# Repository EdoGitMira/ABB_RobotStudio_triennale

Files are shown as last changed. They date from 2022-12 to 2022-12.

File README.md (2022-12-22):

[][License]

<div align = center>

# ABB Robot Studio

*Automation of a two parts automotive manufacturing process* <br>
*Designing / drawing of customized grippers*

<br>

### Team
  
[][Marco] 
[][Edoardo]

<br>
<br>

## Showcase

<br>
       
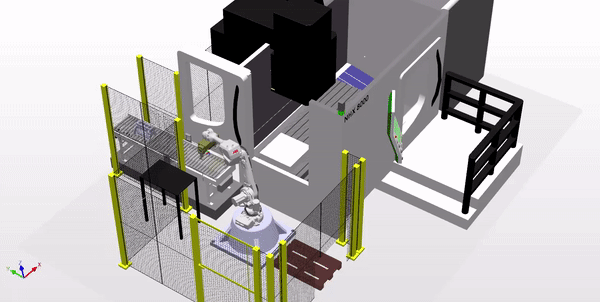
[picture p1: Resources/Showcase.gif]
Showcase


*Accelerated animation showing the entire process*

<br>
<br>

## Implementation

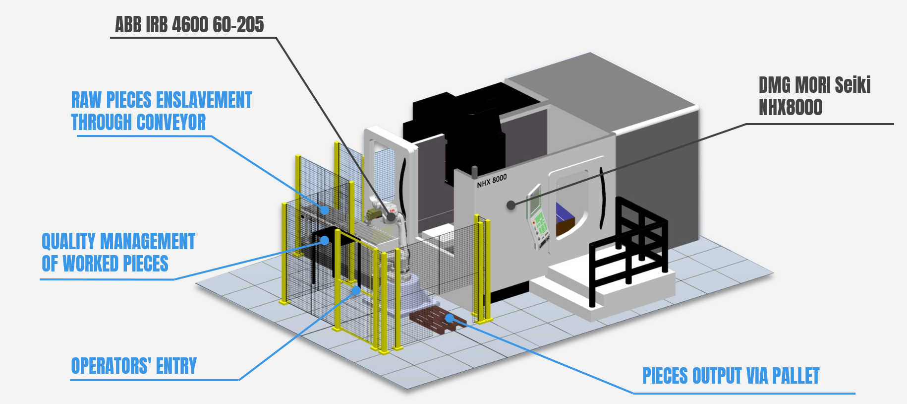
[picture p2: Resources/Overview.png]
Overview


<br>

### Transportation

| *Arrival of New Parts* | *Dispensing of Finished Parts onto Pallet*
|:---:|:---:
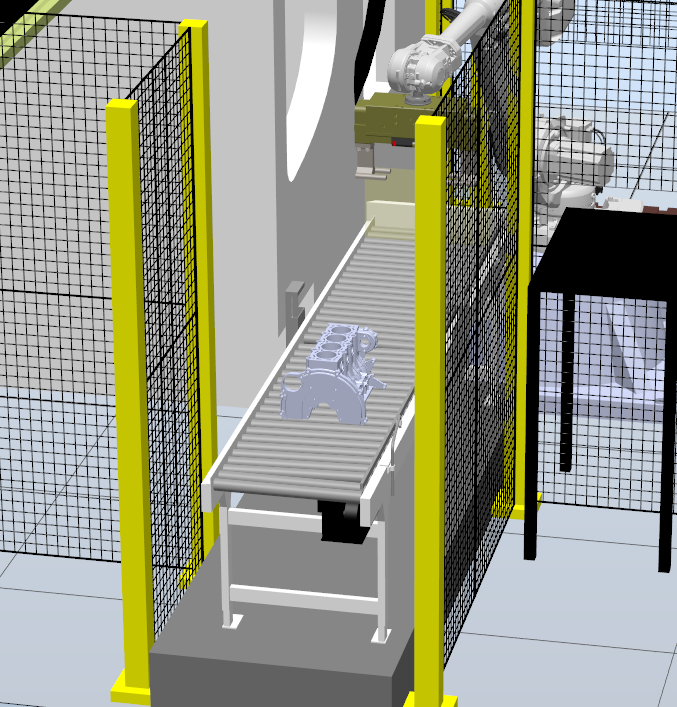
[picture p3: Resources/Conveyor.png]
Conveyor
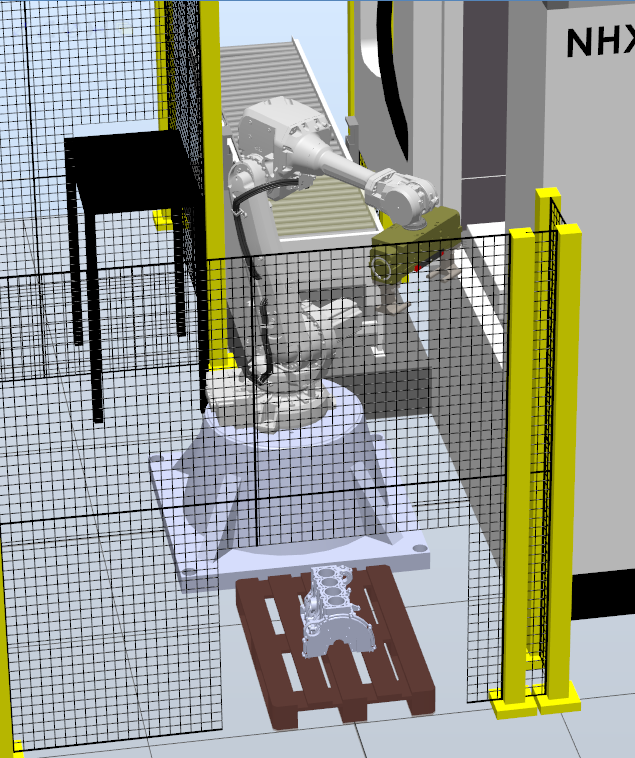
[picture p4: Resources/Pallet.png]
Pallet
|        | 

<br>

### Workpiece Clamping

| XSR201 | XSR202
|:---:|:---:
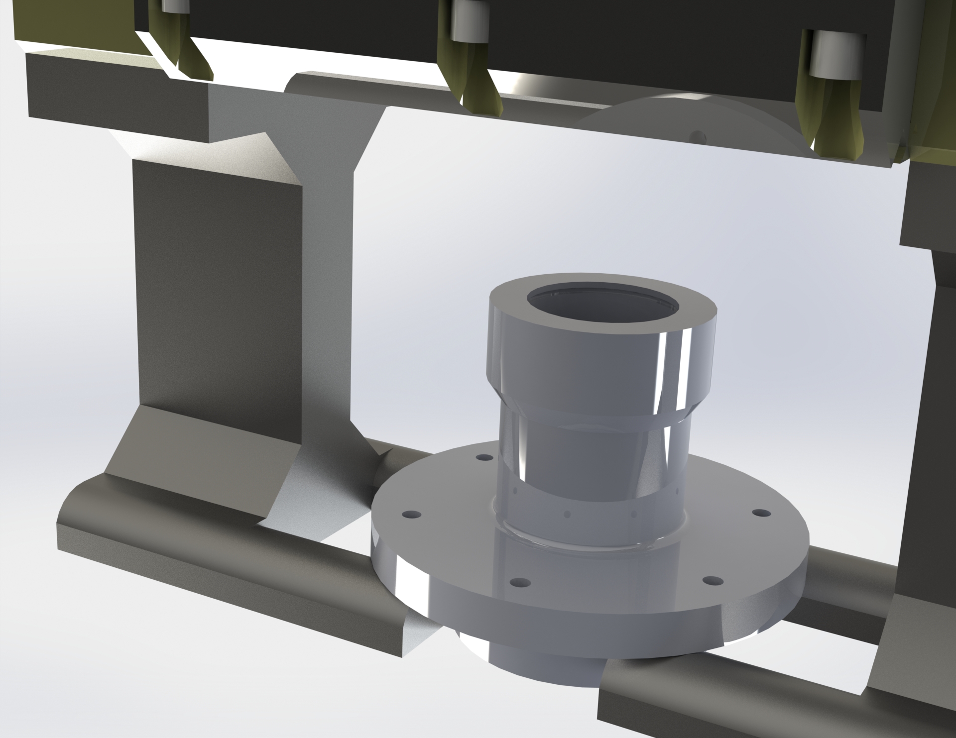
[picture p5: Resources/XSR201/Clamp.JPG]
Clamp 201
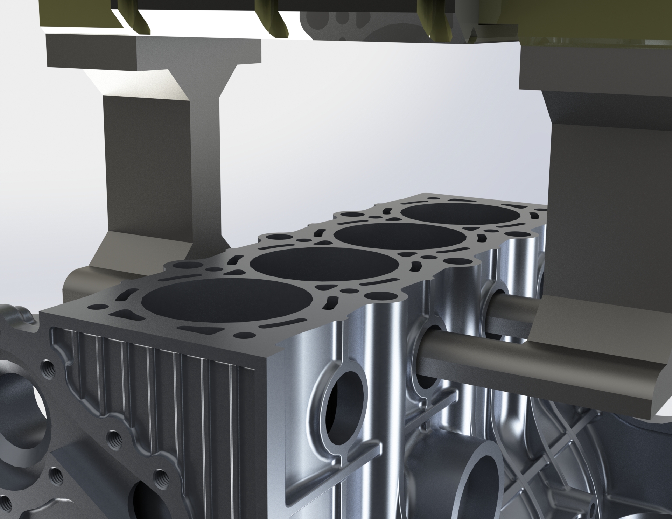
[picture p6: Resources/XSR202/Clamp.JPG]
Clamp 202
|  | 

<br>

### Robot Path

| XSR201 | XSR202
|:---:|:---:
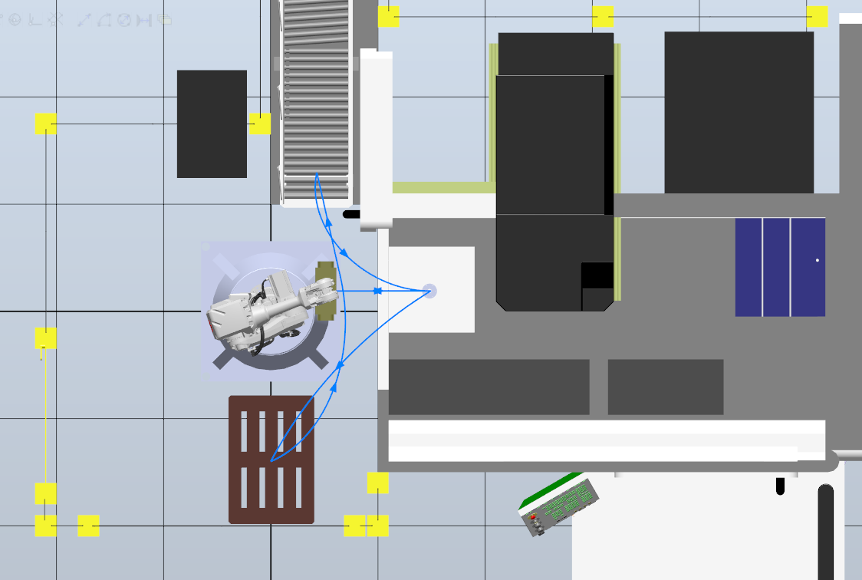
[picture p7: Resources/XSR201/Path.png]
Path 201
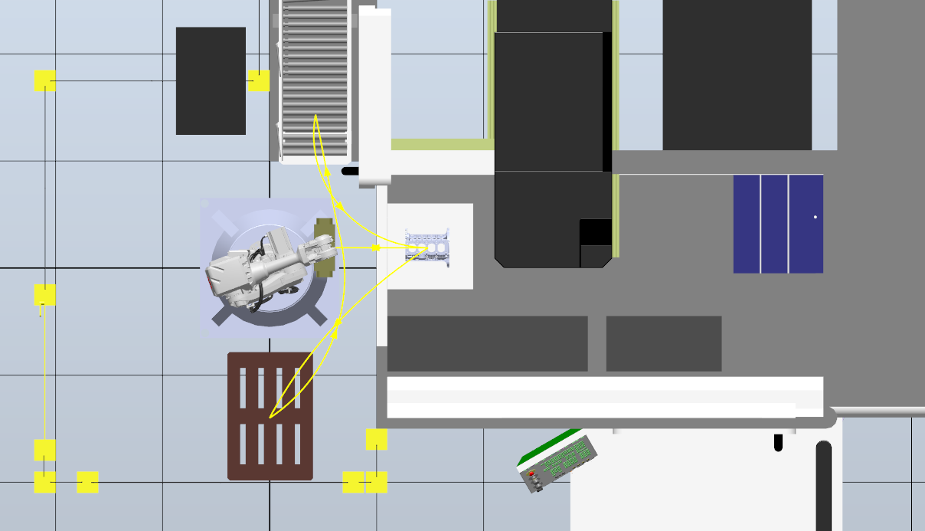
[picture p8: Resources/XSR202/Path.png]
Path 202
|  | 

</div>

<!----------------------------------------------------------------------------->

[Edoardo]: https://github.com/EdoGitMira
[Marco]: https://github.com/marco-milanesi

[License]: LICENSE

<!----------------------------------{ Images }--------------------------------->

[Overview]: Resources/Overview.png
[Showcase]: Resources/Showcase.gif
[Conveyor]: Resources/Conveyor.png
[Pallet]: Resources/Pallet.png

[Clamp 201]: Resources/XSR201/Clamp.JPG
[Path 201]: Resources/XSR201/Path.png

[Clamp 202]: Resources/XSR202/Clamp.JPG
[Path 202]: Resources/XSR202/Path.png

<!---------------------------------{ Badges }---------------------------------->

[Badge License]: https://img.shields.io/badge/License-MIT-yellow.svg?style=for-the-badge

[Badge Edoardo]: https://img.shields.io/badge/Edoardo_Mirandola-8a61c7?style=for-the-badge
[Badge Marco]: https://img.shields.io/badge/Marco_Milanesi-4776c1?style=for-the-badge

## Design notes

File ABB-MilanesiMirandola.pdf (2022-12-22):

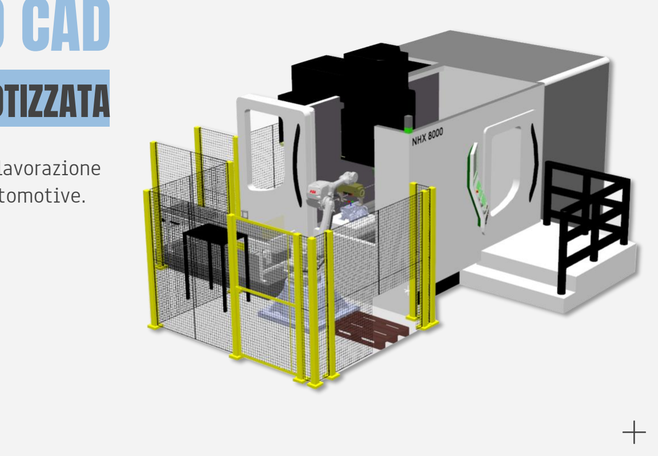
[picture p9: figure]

# PROGETTO ISOLA ROBOTIZZATA

Automazione di un processo di lavorazione meccanica di due particolari automotive.

# LABORATORIO CAD

# Milanesi Marco Mirandola Edoardo

## CONCEPT DELLA CELLA

## SCELTA GRIPPER

## SCELTA ROBOT

## PROGETTAZIONE DELLA CELLA CON IL SW

## PARAMETRI DELLA CELLA

01

02

03

04

05

Milanesi - Mirandola

# LAYOUT

# DELLA CELLA

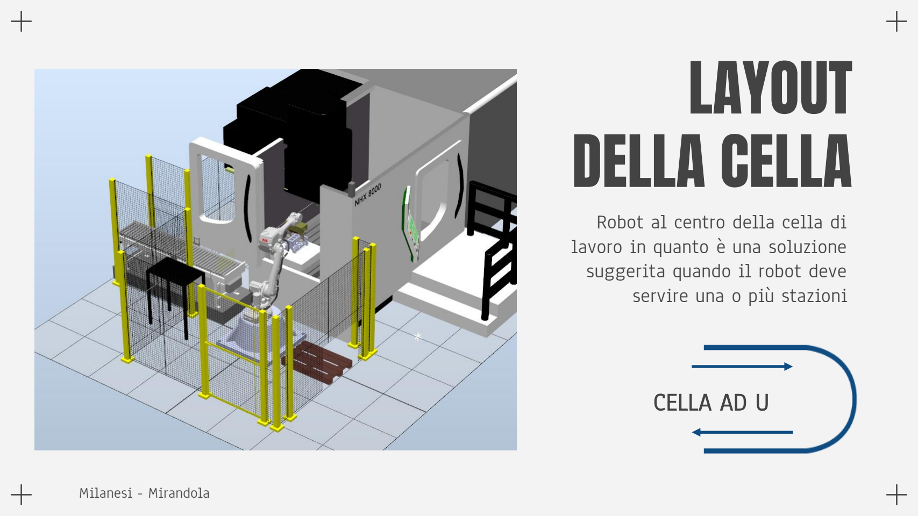
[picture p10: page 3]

## CELLA AD U

Robot al centro della cella di lavoro in quanto è una soluzione suggerita quando il robot deve servire una o più stazioni

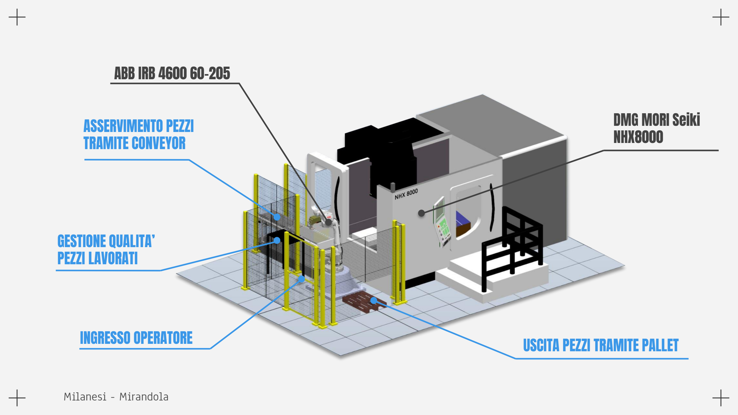
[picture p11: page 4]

DMG MORI Seiki
NHX8000

ABB IRB 4600 60-205

ASSERVIMENTO PEZZI
TRAMITE CONVEYOR

USCITA PEZZI TRAMITE PALLET INGRESSO OPERATORE

GESTIONE QUALITA’
PEZZI LAVORATI

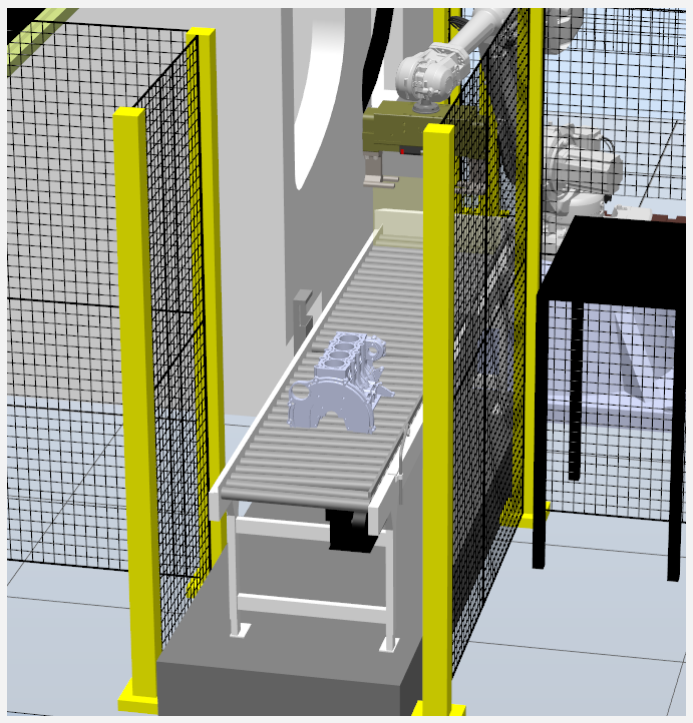
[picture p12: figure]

## Asservimento Pezzi

L’ asservimento pezzi avviene tramite un convogliatore e un PlaneSensor. La simulazione viene azionata dal comando n_MOT / n_XSR201 a seconda del pezzo del pezzo da lavorare.

Se il sensore non rileva la presenza di alcun elemento e non è in corso una lavorazione il convogliatore viene messo in movimento per far sì che un nuovo pezzo arrivi in posizione.

L’istruzione WaitDI FC_Nastro,1 attende che il nastro si arresti prima di procedere

# IMPLEMENTAZIONE DELLA STAZIONE

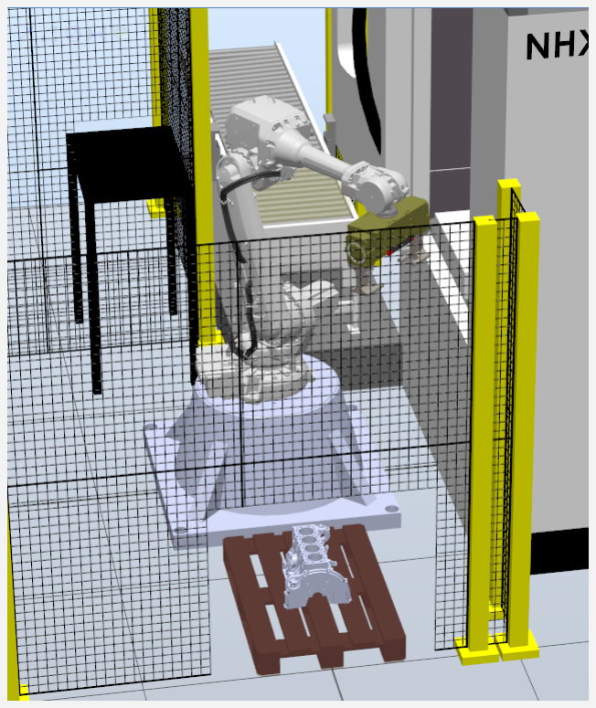
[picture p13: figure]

## Uscita Pezzi

Lo scarico pezzi avviene tramite pallet e un PlaneSensor. Quando il sensore rileva lo scarico del pezzo sul pallet esso può uscire.

Un linear Mover simula l’uscita del pallet che può avvenire tramite un operatore con Transpallet o tramite altro processo automatizzato

Un ulteriore sensore verifica l’effettiva uscita del pallet e inserisce un nuovo pezzo sul conveyor per una simulazione più simile alla realtà.

# IMPLEMENTAZIONE DELLA STAZIONE

## PINZA PARALLELA – SHUNK - 0302120 SPG

# SCELTA GRIPPER

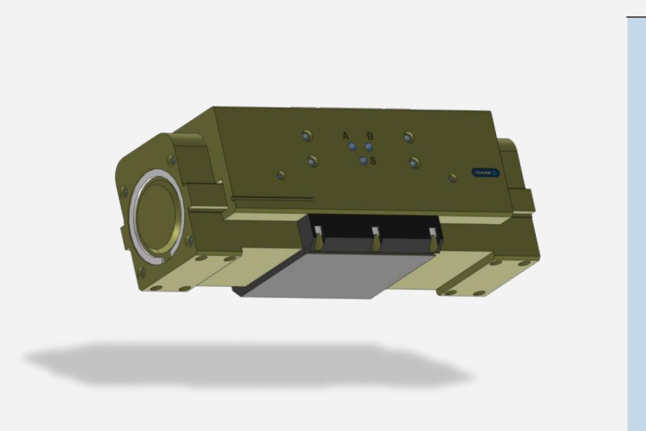
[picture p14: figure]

CORSA PER GRIFFA | 95 | mm
PESO | 35 | Kg
PESO DEL PEZZO
RACCOMANDATO | 50 | Kg

LUNGHEZZA GRIFFE
MASSIMA CONSENTITA | 500 | mm

MASSA MAX. CONSENTITA
PER GRIFFA | 500 | mm

PRINCIPALI PARAMETRI PRESI IN CONSIDERAZIONE

# PRESA PEZZO XSR202

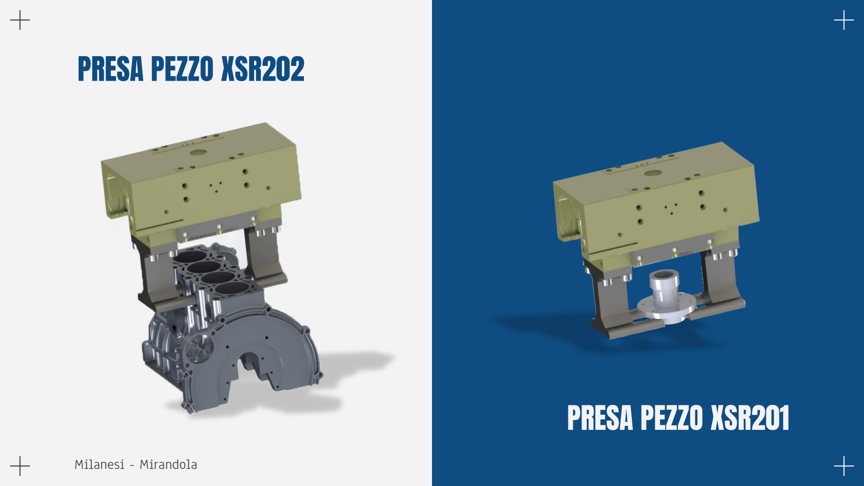
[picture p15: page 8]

# PRESA PEZZO XSR201

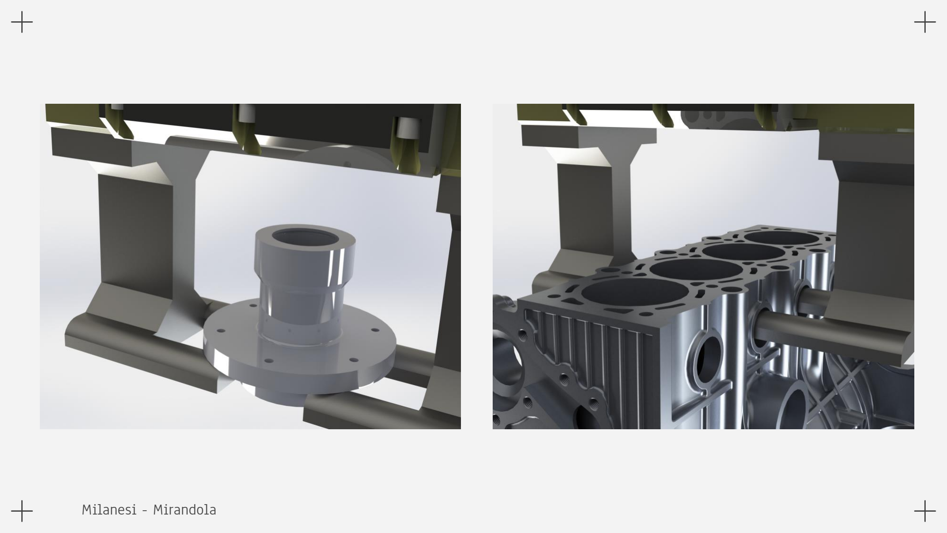
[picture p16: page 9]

# SCELTA DEL ROBOT

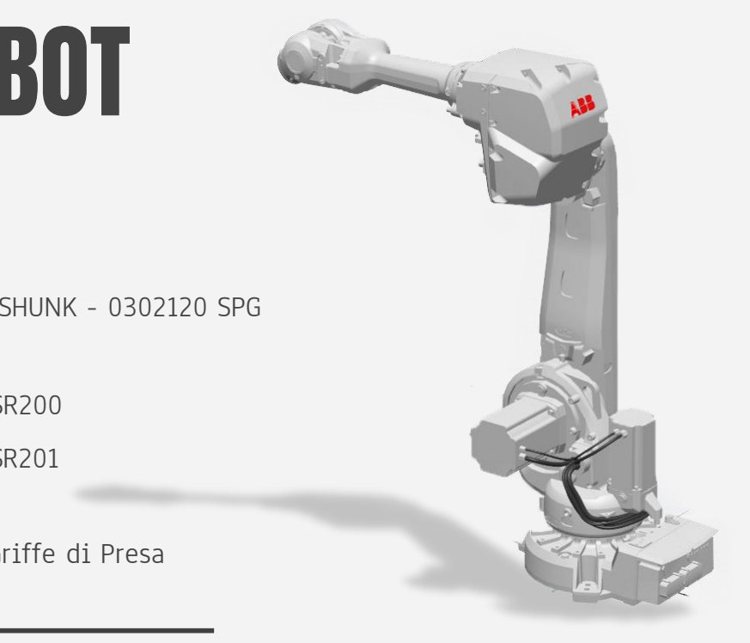
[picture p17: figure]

35 Kg Peso Gripper SHUNK - 0302120 SPG

17 Kg
0,5 Kg
| Peso Pezzo XSR200

# Calcolo del payload

Peso Pezzo XSR201

ROBOT ABB IRB 4600 60-205

4 Kg | Peso Totale Griffe di Presa
56 Kg | 60 Kg

# PROGETTAZIONE DELLA CELLA

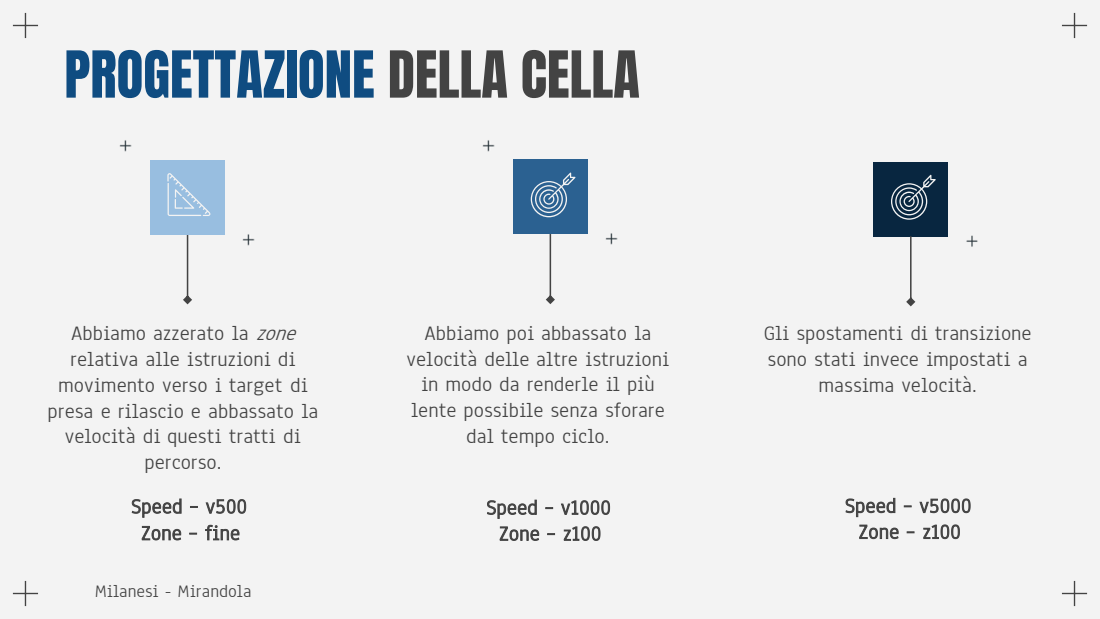
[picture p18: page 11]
Speed – v1000 Zone – z100; Speed – v5000 Zone – z100

Abbiamo azzerato la zone
relativa alle istruzioni di
movimento verso i target di
presa e rilascio e abbassato la
velocità di questi tratti di
percorso.
Speed – v500
Zone – fine

Abbiamo poi abbassato la
velocità delle altre istruzioni
in modo da renderle il più
lente possibile senza sforare
dal tempo ciclo.

Gli spostamenti di transizione
sono stati invece impostati a
massima velocità.

# LOGICA DEL PROGRAMMA

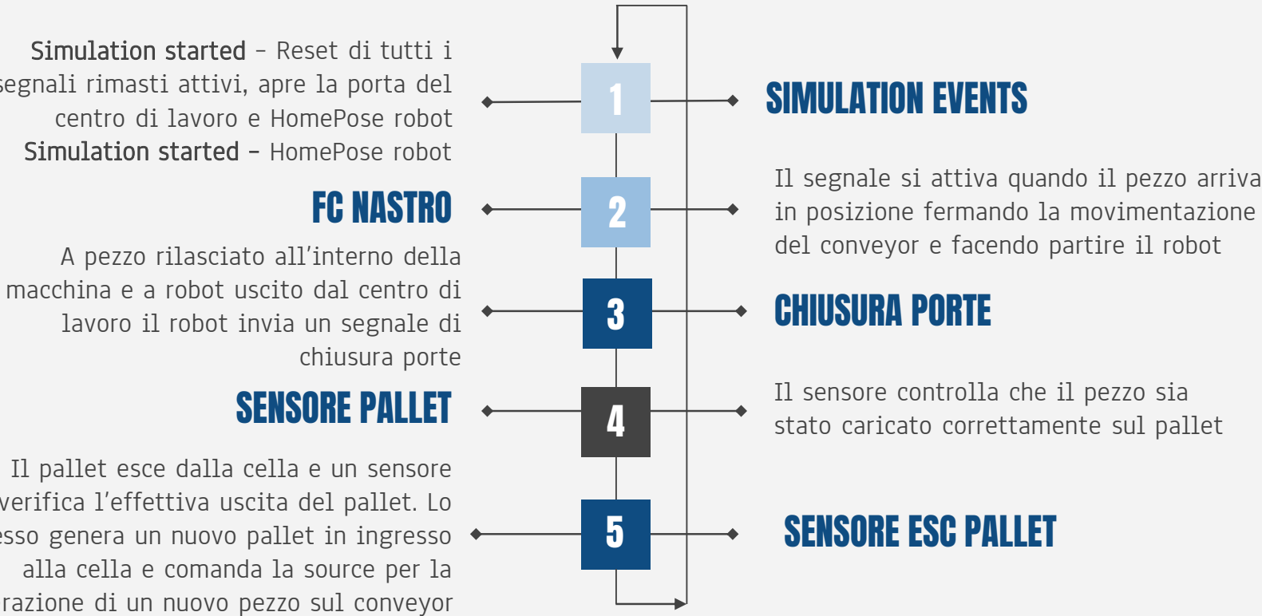
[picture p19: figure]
Simulation started – Reset di tutti i; centro di lavoro e HomePose robot Simulation started – HomePose robot; Il pallet esce dalla cella e un sensore; alla cella e comanda la source per la; A pezzo rilasciato all’interno della macchina e a robot uscito dal centro di lavoro il robot invia un segnale di chiusura porte; in posizione fermando la movimentazione del conveyor e facendo partire il robot; Il sensore controlla che il pezzo sia stato caricato correttamente sul pallet; SIMULATION EVENTS; FC NASTRO; CHIUSURA PORTE; SENSORE ESC PALLET; SENSORE PALLET

segnali rimasti attivi, apre la porta del

verifica l’effettiva uscita del pallet. Lo stesso genera un nuovo pallet in ingresso

generazione di un nuovo pezzo sul conveyor

Il segnale si attiva quando il pezzo arriva

# PATH

PEZZO XSR 202 | PEZZO XSR 201

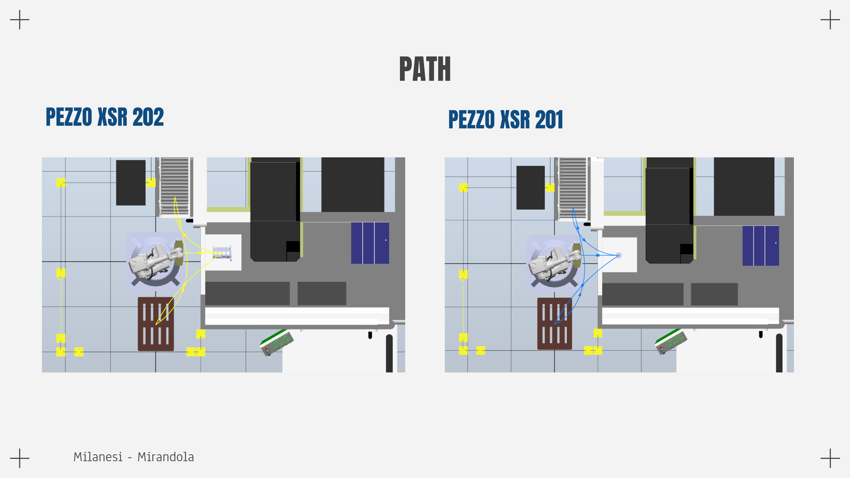
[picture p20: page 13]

# TEMPI E RITMI PRODUTTIVI

Ritmo attività
produttiva

Somma dei tempi di attesa, tempi di giacenza e tempi di trasporto

Tempo che trascorre tra
l’inizio e la fine di una
lavorazione
60 s / pezzo | 56 s
TACKT TIME | TEMPO CICLO | TEMPO DI TRANSITO
CONVEYOR | 4 s
LAVORAZIONE MACCHINA | 45 s
USCITA PEZZO PALLET | 2 s

51 s

CONVEYOR -
MACCHINA 1,8 s

MACCHINA -
PALLET 2,5 s

### 8 h/turno

### 480 pezzi turno

# LABORATORIO CAD

Automazione di un processo di lavorazione meccanica di due particolari automotive. Progettazione di un’isola robotizzata tramite il software ABB Robot Studio

### Milanesi Marco - Mirandola Edoardo

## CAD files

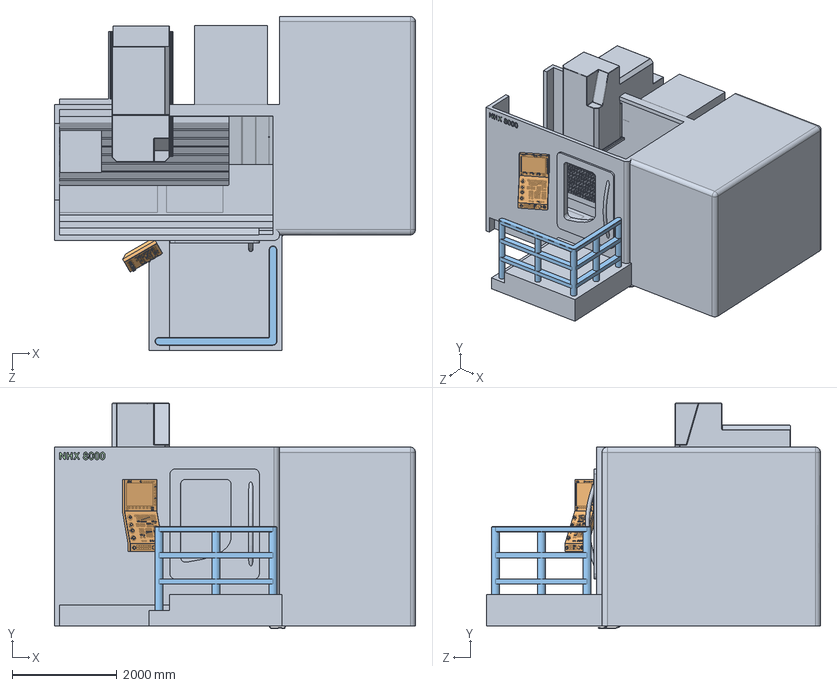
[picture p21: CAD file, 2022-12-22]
disegni_solidworks/assieme_macchina_nhx8000.SLDASM
6904.5 x 4313.0 x 6388.5 mm
macchina
tastiera
ringhiera
logo

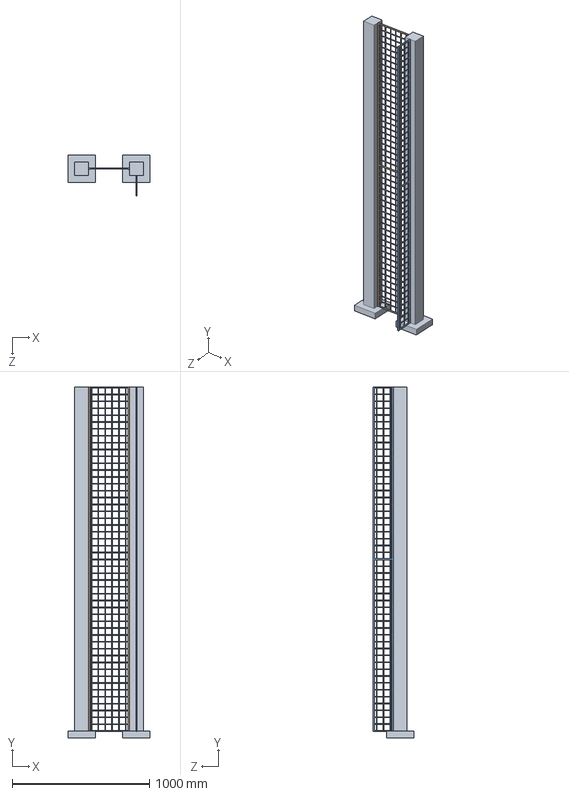
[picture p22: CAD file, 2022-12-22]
disegni_solidworks/bariera_angolo.SLDASM
600.0 x 2555.0 x 300.0 mm
palo_barriera x 2
rete 300
rete200

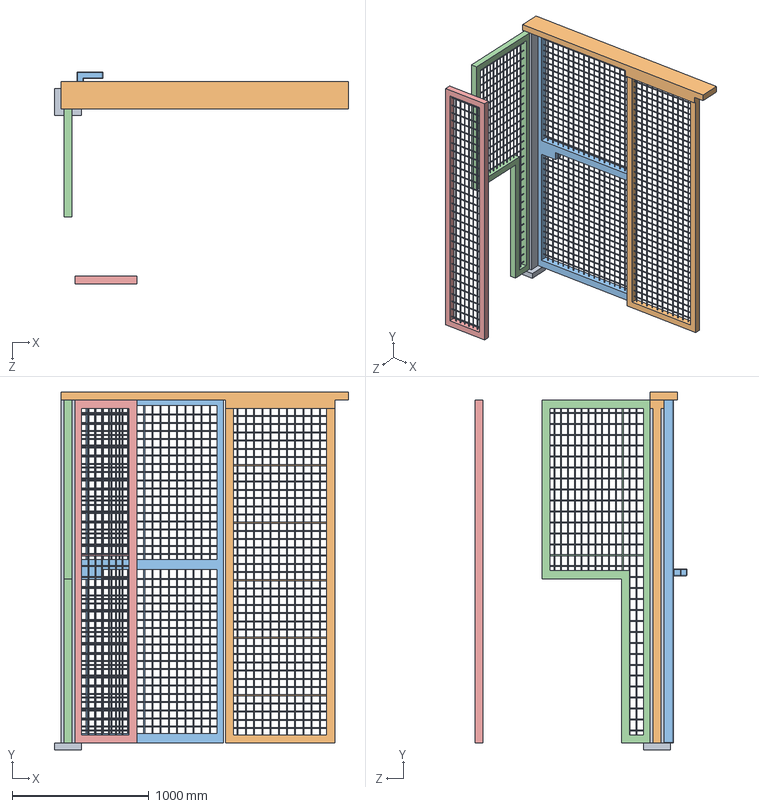
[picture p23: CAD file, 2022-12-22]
disegni_solidworks/Assieme1.SLDASM
2151.0 x 2615.0 x 1550.0 mm
palo_barriera
rete1m_c

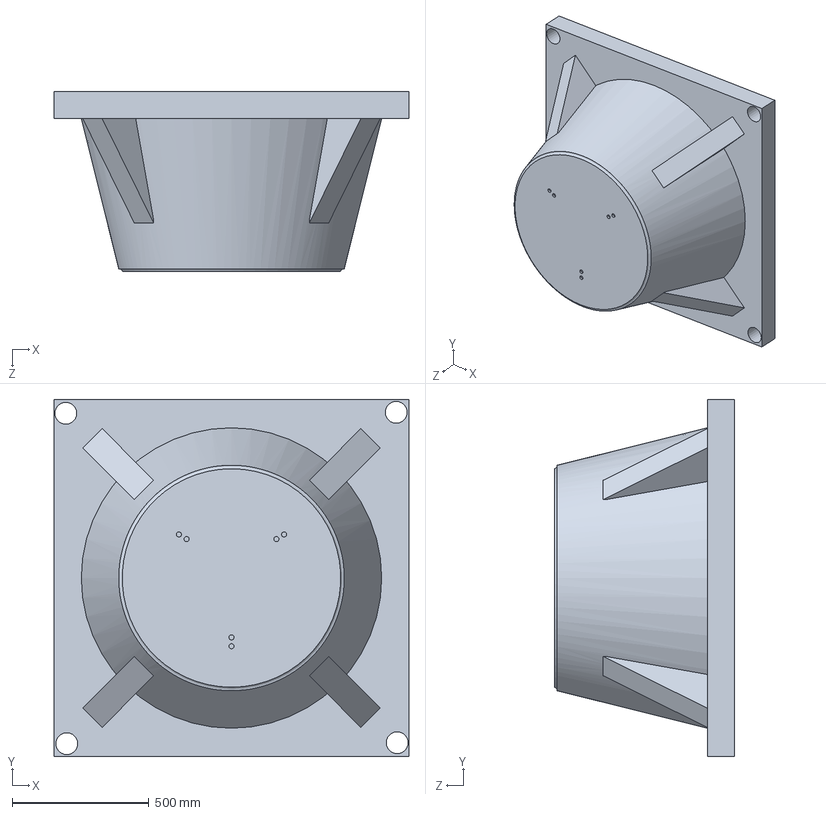
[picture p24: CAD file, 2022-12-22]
disegni_solidworks/Basamento.SLDASM
1300.0 x 1307.5 x 660.0 mm

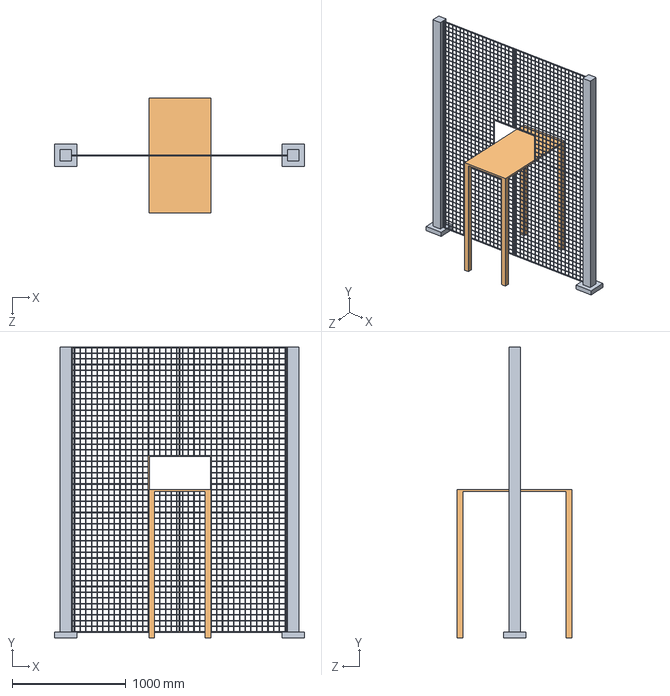
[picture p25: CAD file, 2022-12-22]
disegni_solidworks/bariera_2m - porta.SLDASM
2200.0 x 2556.2 x 1007.5 mm
palo_barriera x 2
rete_2m-porta

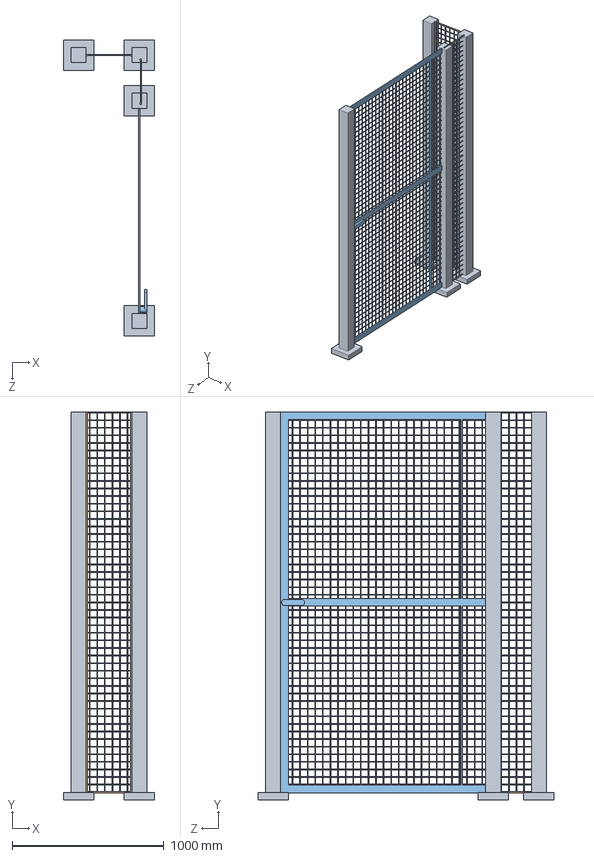
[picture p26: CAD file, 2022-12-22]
disegni_solidworks/bariera_porta_angolo.SLDASM
600.0 x 2555.0 x 1950.0 mm
palo_barriera x 4
rete 300 x 2
rete2m

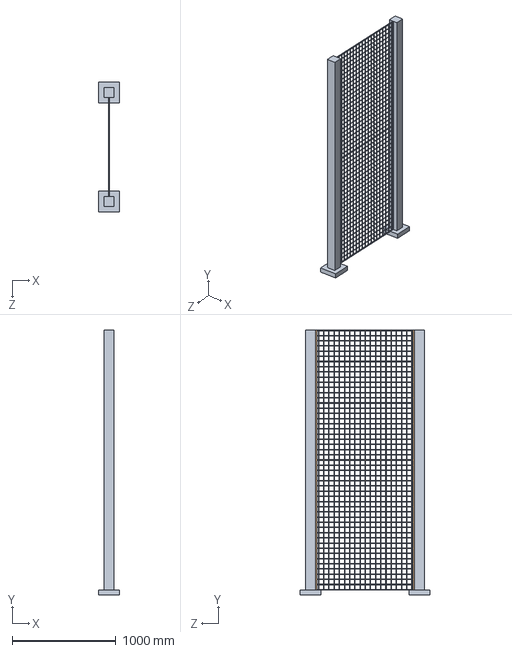
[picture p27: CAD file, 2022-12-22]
disegni_solidworks/bariera_1m.SLDASM
200.0 x 2555.0 x 1250.0 mm
palo_barriera x 2
rete_1m

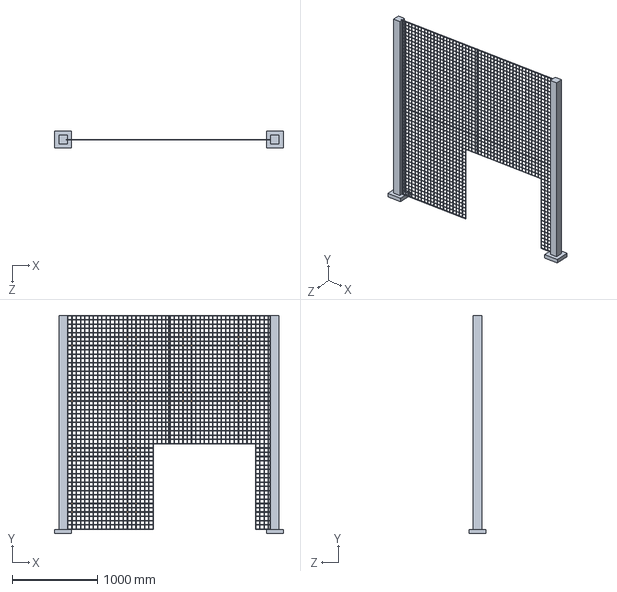
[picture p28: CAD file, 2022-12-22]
disegni_solidworks/bariera_2m.SLDASM
2682.5 x 2557.5 x 200.0 mm
palo_barriera x 2
rete_2m

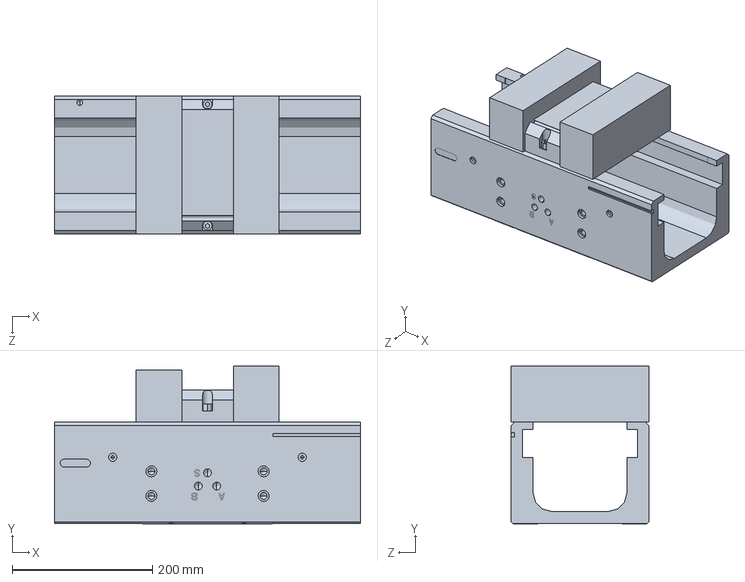
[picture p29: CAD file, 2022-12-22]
gripper/SCHUNK_0302120_SPG_100_SDV_P__950ohne_8.SLDPRT
436.0 x 225.1 x 196.0 mm

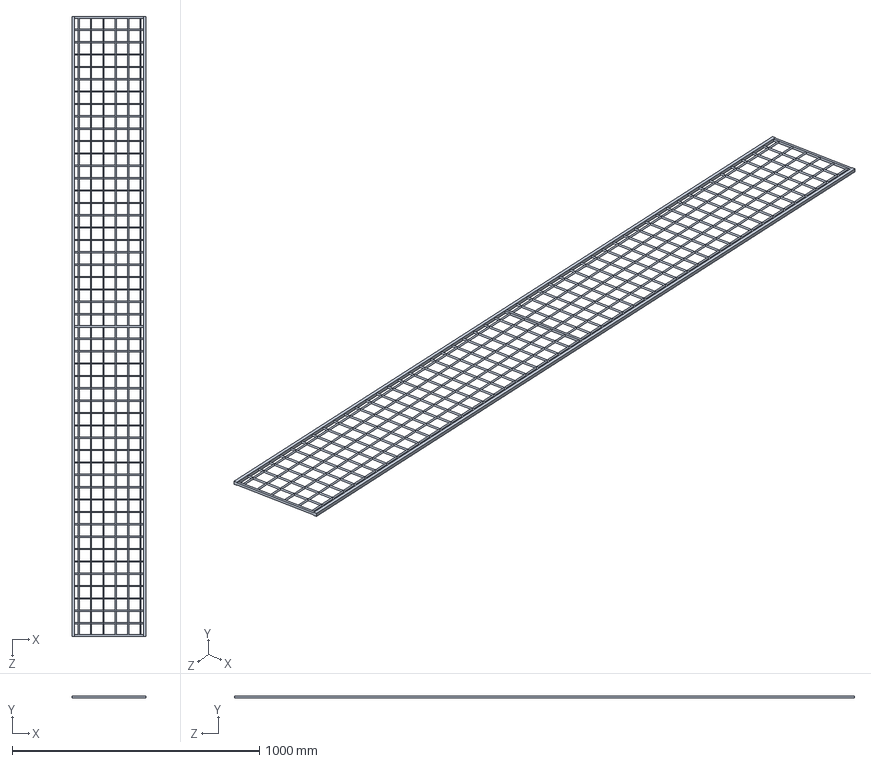
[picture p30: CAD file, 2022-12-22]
disegni_solidworks/rete 300.SLDPRT
300.0 x 10.0 x 2507.5 mm

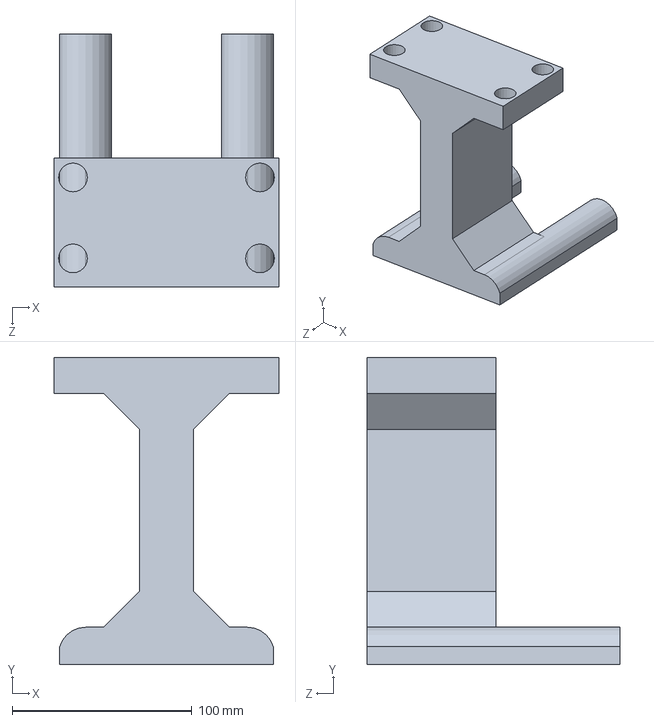
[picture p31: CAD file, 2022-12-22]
gripper/griffa.SLDPRT
125.0 x 170.7 x 140.8 mm

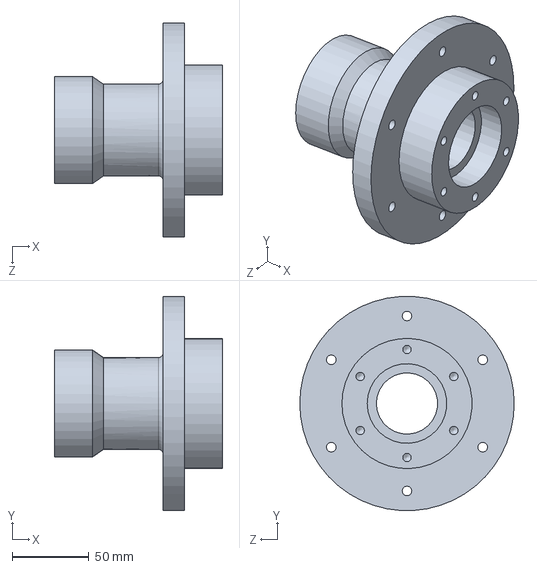
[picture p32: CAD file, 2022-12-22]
gripper/XSR201_lavorato.SLDPRT
110.0 x 139.7 x 140.0 mm

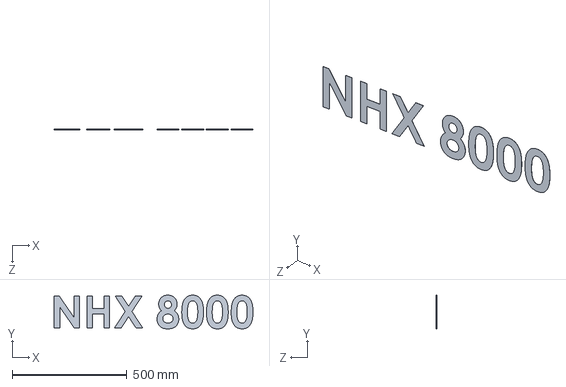
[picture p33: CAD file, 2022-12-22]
disegni_solidworks/logo.SLDPRT
866.9 x 147.2 x 0.4 mm

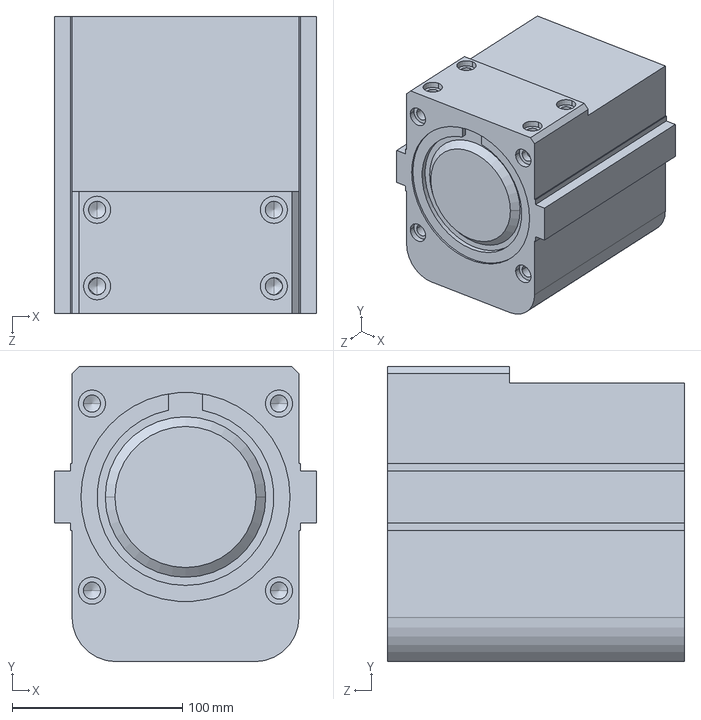
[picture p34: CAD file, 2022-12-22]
gripper/SCHUNK_0302120_SPG_100_SDV_P__950ohne_3.SLDPRT
154.2 x 173.7 x 174.7 mm

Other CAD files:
gripper/SCHUNK_0302120_SPG_100_SDV_P__950ohne_6.SLDPRT
disegni_solidworks/XSR201_nonlavorato.SLDPRT
disegni_solidworks/palo_barriera.SLDPRT
disegni_solidworks/rete_1m.SLDPRT
disegni_solidworks/Basamento.SLDPRT
disegni_solidworks/Parte1^bariera_1m.SLDPRT
disegni_solidworks/rete1m_c.SLDPRT
disegni_solidworks/rete200.SLDPRT
disegni_solidworks/rete2m.SLDPRT
disegni_solidworks/rete_porta.SLDPRT
disegni_solidworks/ringhiera.SLDPRT
